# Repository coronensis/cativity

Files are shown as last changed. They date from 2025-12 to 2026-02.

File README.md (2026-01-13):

CatIVity - CAT protocol (Icom CI-V) based remote VFO tuner

This is a new iteration of CatIVity.
It is WORK IN PROGRESS and not yet fully tested.

You can find the previous version (tested and working) under v1.

## Hardware

## Software

## Development environment

Developed under GNU/Linux - [Debian](https://www.debian.org/) (Desktop) and [Raspbian](https://www.raspberrypi.org/downloads/raspbian/) (Raspberry Pi)
distributions

Toolchain and other tools/utilities used:

Desktop

- avr-gcc

Raspberry Pi

- avr-gcc
- avrdude

The provided Makefile is meant to be used on a Raspberry Pi.
Note that the reset pin of the ATmega328P is connected to pin 21 of the Raspberry
and is pulled low before starting to flash the binary to the microcontroller.

## References

- Icom's CI-V protocol specification [Computer Interface, version V](https://www.icomeurope.com/wp-content/uploads/2020/08/IC-705_ENG_CI-V_1_20200721.pdf)
- Xiegu G90 CAT protocol specification [Xiegu G90, CAT and digital modes](https://radioddity.s3.amazonaws.com/Radioddity%20-%20Xiegu%20G90%2C%20CAT%20and%20Digital%20modes%20V1.0_20210623.pdf)

## Homepage And Source Code Repository

https://github.com/coronensis/cativity

## Contact

Feel free to reach out if you run into problems building this project or want to extend or port it.

Helmut Sipos, YO6ASM <yo6asm@gmail.com>

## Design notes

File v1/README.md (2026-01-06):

CatIVity - CAT protocol (Icom CI-V) based remote VFO tuner

## Background

I recently got my amateur radio license and bought a Xiegu G90 as my first transceiver
to have something to play around with. The radio is well regarded in the ham community
and indeed does a pretty decent job for its price. That is, until it comes to tuning.

Like many other simple QRP transceivers, it has just a rudimentary VFO tuner that uses
a cheap mechanical rotary encoder with an even cheaper plastic knob mounted on it.

Such encoders tend to give up life really soon when heavily used. Additionally it is
next to impossible to efficiently tune up and down the bands. The aforementioned plastic knob
doesn't lend itself to quick operation and either you risk cramps in your fingers
or annoying delays/interruptions when changing the frequency decimal position that is
updated when you turn the knob.

As tuning around the bands looking for interesting stations to make contact with is
the main activity (at least speaking for myself) when "playing radio" that tuning behavior
of the G90 is plainly unacceptable.

Xiegu addresses that issue by selling a companion device (GSOC Touch Screen Controller)
that has a larger screen and decent knobs but that:

```
a.) Doubles the price of the setup (at which point you could look into buying an Icom 7300)
b.) Needs to be carried around as well if you are operating mostly portable, like myself.
```

As I was willing to accept neither a.) nor b.) I looked for an alternative and came up
with the solution implemented in this project.

## Solution

The G90 can be controlled via UART using a CAT protocol (more precisely: an Icom CI-V flavor)
so it is easy to implement something on a microcontroller that has a UART on it (alternatively
you can implement a "bit banged" software-UART if it doesn't) and that somehow determines the
frequency to be set, then instructs the G90 to tune to the determined frequency.

I chose to use two potentiometers (potentiometers are dirt cheap and can easily be replaced
when worn out) as the tuning knobs and to control with them the lower 5 decimal position of the
frequency.  More precisely the upper 4 of the lower 5 as the last decimal position is always 0 -
the minimum tuning step for the G90 is 10 Hz.
As the multifunction knob on the G90 can be configured to set the 6th decimal point (100k frequency
step) and there are buttons to change the bands, tuning becomes quite fluent.
The only awkward thing about that decision is that a potentiometer needs to be "reset" manually by
turning it back to its initial position. Alternatively you can tune one time upwards to 99 then
downwards to 0, which makes no difference to the frequency range scanned.

The implementation is pretty straight forward:

First synchronize with the G90 to get the current frequency it is tuned to. That frequency can
change anytime due to user intervention so it needs to be fetched every time before sending
a "SetActiveVFOFrequency" command. The CI-V command to get the frequency is "GetActiveVFOFrequency".

Once the current frequency is known, read the value of the ADC channels to which the two potentiometers
are attached (let's call them (L)eft and (R)ight). The potentiometers form a voltage divider and the
value read by the ADC reflects their relative position to zero volt. When the potentiometer is completely
"down" the ADC reads 0, conversely it will read the maximum value 1024 (the ADC works with 10 bits)
when the pot is completely "up". Dividing the ADC value by 10 brings it into range for what is needed
(0..99) and as a nice side effect also acts as a debouncing mechanism.

The next step is to construct the "SetActiveVFOFrequency" message with the read and translated ADC values
and send it to the radio then wait for the response of the radio. Then "rinse and repeat".

Example:

Lets say the current frequency set on the radio is 14198760 Hz. The ADC value 23 for the Left pot
and 45 for the right pot were read. Next the value 98 in the current frequency is substituted for 23
and 76 for 45 resulting in the frequency-to-be set 14123450 Hz.

```
 14 198 760 <- Currently frequency on the radio
     || ||
     23 45  <- Left and Right pot values read form ADC
     || ||
 14 123 450 <-  Final frequency that will be requested via "SetActiveVFOFrequency"
```

This frequency is translated into the specific protocol message byte sequence (look into the protocol
specification (links in the references section below) for how the data is encoded) and sent to the G90.

The implementation was done on a spare ATmega328P which has a hardware UART and ADC on it.
It is less than 300 lines of code (including comments and blanks).

While this toy is Xiegu G90 specific it should be really easy to port it to any other radio
that supports the CI-V protocol.

73! Helmut, YO6ASM

## Hardware

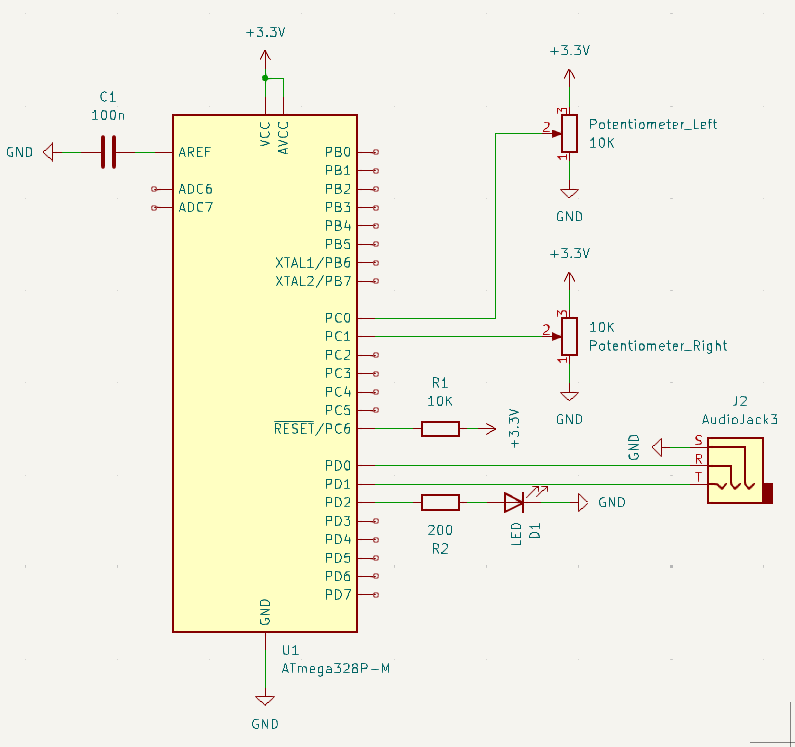
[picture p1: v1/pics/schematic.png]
CatIVity Schematic


```
1 x Atmel (Microchip) ATmega328P microcontroller - PDIP package
1 x red LED
2 x 10K potentiometer
1 x 100n capacitor
2 x 10K resistor
1 x 200ohm resistor
1 x Stereo audio jack
2 x Stereo audio plug (to make the cable to connect to the G90)

2 x Platic knob (recycled original G90 knobs)
1 x Platic housing (in this example: an old bicycle tire repair kit)
```

## Software

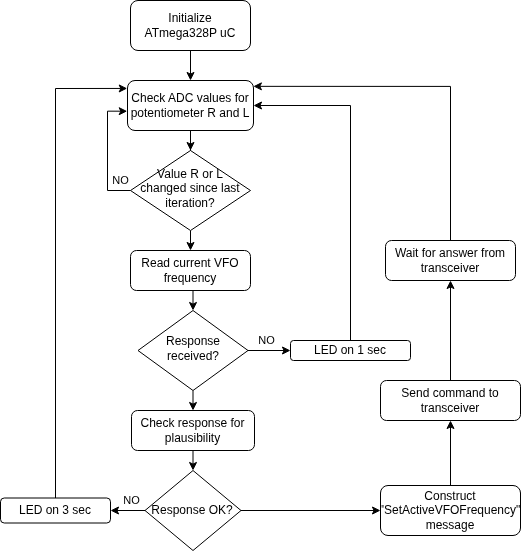
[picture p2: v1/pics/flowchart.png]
CatIVity Flowchart


## TODO

```
In a next iteration replace the potentiometers with a single optical rotary encoder and a
large tuning knob.
Add an LCD display for displaying the frequency and other status information.
Add a few buttons and make their function configurable via a dedicated PC application.
Larger housing to accommodate the additional space needed by the above additions.
```

## Pictures

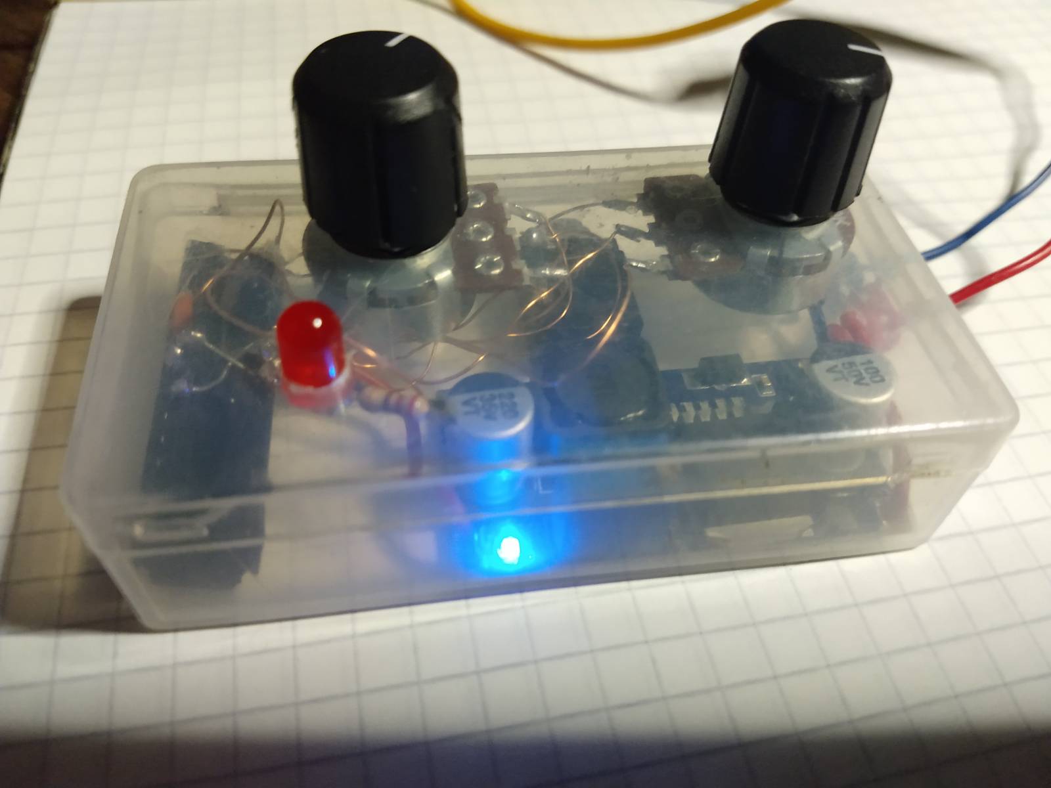
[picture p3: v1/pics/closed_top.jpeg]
Top

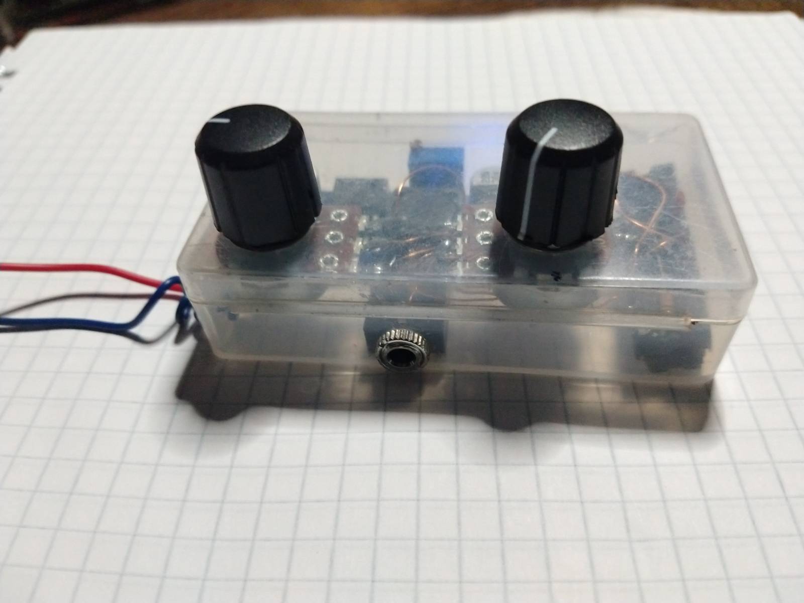
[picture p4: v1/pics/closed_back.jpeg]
Back

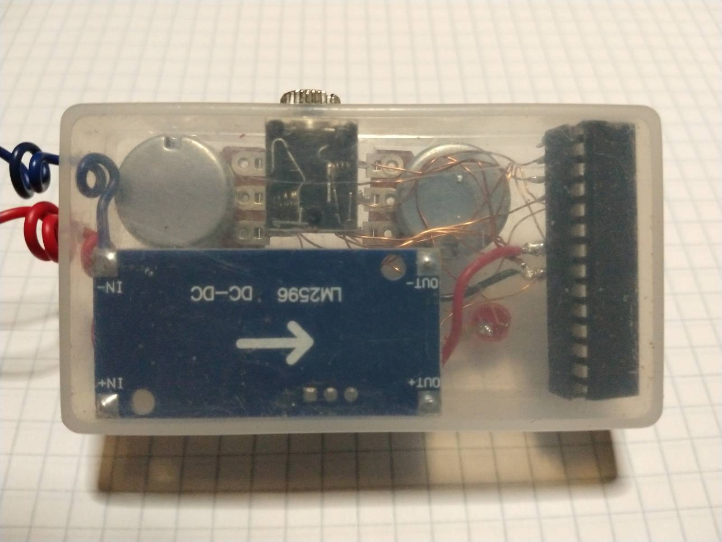
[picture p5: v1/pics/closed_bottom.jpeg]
Bottom

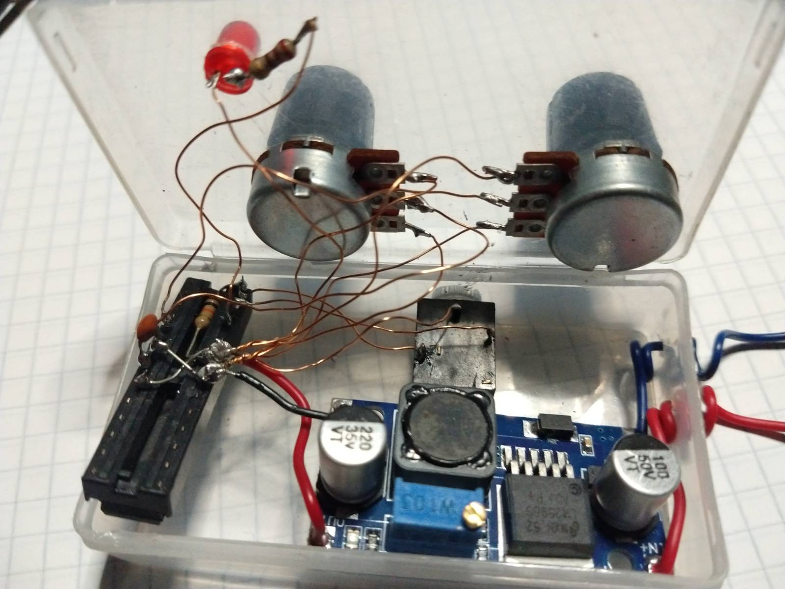
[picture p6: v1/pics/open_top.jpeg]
Open

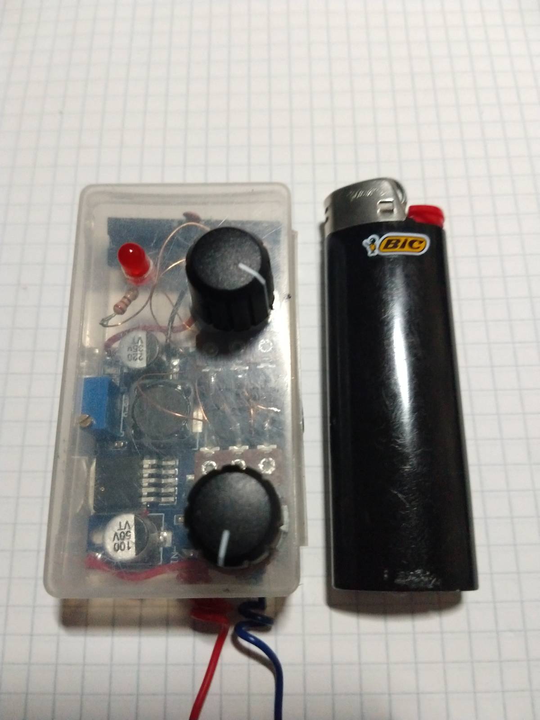
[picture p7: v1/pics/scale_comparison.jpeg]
Size


## Development environment

Developed under GNU/Linux - [Debian](https://www.debian.org/) (Desktop) and [Raspbian](https://www.raspberrypi.org/downloads/raspbian/) (Raspberry Pi)
distributions

Toolchain and other tools/utilities used:

Desktop

- avr-gcc

Raspberry Pi

- avr-gcc
- avrdude

The provided Makefile is meant to be used on a Raspberry Pi.
Note that the reset pin of the ATmega328P is connected to pin 21 of the Raspberry
and is pulled low before starting to flash the binary to the microcontroller.

## References

- Icom's CI-V protocol specification [Computer Interface, version V](https://www.icomeurope.com/wp-content/uploads/2020/08/IC-705_ENG_CI-V_1_20200721.pdf)
- Xiegu G90 CAT protocol specification [Xiegu G90, CAT and digital modes](https://radioddity.s3.amazonaws.com/Radioddity%20-%20Xiegu%20G90%2C%20CAT%20and%20Digital%20modes%20V1.0_20210623.pdf)

## Homepage And Source Code Repository

https://github.com/coronensis/cativity

## Contact

Feel free to reach out if you run into problems building this project or want to extend or port it.

Helmut Sipos, YO6ASM <yo6asm@gmail.com>

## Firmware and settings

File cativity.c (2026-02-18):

/*
 * CatIVity - CAT protocol (Icom CI-V) based remote VFO tuner
 *
 * Copyright (c) 2026 Helmut Sipos, YO6ASM <yo6asm@gmail.com>
 * All rights reserved.
 *
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
 * THIS SOFTWARE IS PROVIDED BY THE COPYRIGHT HOLDERS AND CONTRIBUTORS "AS IS" AND
 * ANY EXPRESS OR IMPLIED WARRANTIES, INCLUDING, BUT NOT LIMITED TO, THE IMPLIED
 * WARRANTIES OF MERCHANTABILITY AND FITNESS FOR A PARTICULAR PURPOSE ARE
 * DISCLAIMED. IN NO EVENT SHALL THE COPYRIGHT OWNER OR CONTRIBUTORS BE LIABLE FOR
 * ANY DIRECT, INDIRECT, INCIDENTAL, SPECIAL, EXEMPLARY, OR CONSEQUENTIAL DAMAGES
 * (INCLUDING, BUT NOT LIMITED TO, PROCUREMENT OF SUBSTITUTE GOODS OR SERVICES;
 * LOSS OF USE, DATA, OR PROFITS; OR BUSINESS INTERRUPTION) HOWEVER CAUSED AND
 * ON ANY THEORY OF LIABILITY, WHETHER IN CONTRACT, STRICT LIABILITY, OR TORT
 * (INCLUDING NEGLIGENCE OR OTHERWISE) ARISING IN ANY WAY OUT OF THE USE OF THIS
 * SOFTWARE, EVEN IF ADVISED OF THE POSSIBILITY OF SUCH DAMAGE.
 */

#include <avr/io.h>
#include <avr/interrupt.h>
#include <util/delay.h>
#include <stdint.h>

// States of the indicator LED
#define LED_OFF                      0
#define LED_ON                       1

// UART default baudate
#define UART_BAUDRATE                19200

// CI-V protocol elements
#define CIV_PREAMBLE                 0xFE
#define CIV_TRANSCEIVER_ADDRESS      0x70
#define CIV_CONTROLLER_ADDRESS       0xE0
#define CIV_END_OF_MESSAGE           0xFD
#define CIV_GET_ACTIVE_VFO_FREQUENCY 0x03
#define CIV_SET_ACTIVE_VFO_FREQUENCY 0x05

// Supported VFO frequency range 0.5 - 30.0 MHz
#define VFO_FRQUENCY_MIN             500000
#define VFO_FRQUENCY_MAX             30000000

// Pulses per rotation (x 2 as there is one on 'A' AND 'B')
#define ROTARY_ENCODER_PULSES_PER_ROTATION (600 * 2)

// Number of complete rotations per second. Determines the tuning steps.
// The faster the knob is spun, the lager the tuning steps.
volatile uint8_t gRotationsPerSecond = 0;

// RX buffer
volatile uint8_t gUartRXBuffer[64];
// Counter indicating how many bytes are in the RX buffer
volatile uint8_t gUartRXBytes = 0;

// The VFO frequency
volatile uint32_t gVFOFrequency = 0;
// Frequency increment/decrement step
volatile uint8_t gVFOFrequencyStep = 0;
// VFO synchronized with tranceiver indicator flag
volatile uint8_t gVFOFrequencyValid = 0;

// Number of pulses per time unit (1000ms) received from the rotary encoder
volatile uint16_t gEncoderPulses = 0;

// VFO frequency tuning increment/decrement steps
const uint8_t gTuningSteps[] = {1, 2, 3, 4, 5, 10};
#define TUNING_STEPS_IDX_MAX ((sizeof(gTuningSteps)/sizeof(gTuningSteps[0])) - 1)

// Keeps the time since last sync with the transceiver
volatile uint8_t gSecondsSinceLastSync = 0;

// External INT0 (PD2, rotary encoder 'A') interrupt service routine
ISR(INT0_vect)
{
    gEncoderPulses++;

    // Rotation RIGHT?
    if (bit_is_set(PIND, PIND3)) {
        gVFOFrequency += gVFOFrequencyStep;
    }
}

// External INT1 (PD3, rotary encoder 'B') interrupt service routine
ISR(INT1_vect)
{
    gEncoderPulses++;

    // Rotation LEFT?
    if (bit_is_set(PIND, PIND2)) {
        gVFOFrequency -= gVFOFrequencyStep;
    }
}

// UART RX interrupt service routine
ISR(USART_RX_vect)
{
    // Copy the received byte inito the buffer if there is space left
    // Increment the counter indicating how many bytes are in the buffer
    if (gUartRXBytes < sizeof(gUartRXBuffer)) {
        gUartRXBuffer[gUartRXBytes] = UDR0;
        gUartRXBytes++;
    }
}

// Timer1 overflow interrupt service routine
ISR(TIMER1_OVF_vect)
{
    // Setup for new timer overflow interrupt after 1000ms
    TCNT1H = 0x85;
    TCNT1L = 0xEE;

    gSecondsSinceLastSync++;

    gRotationsPerSecond = gEncoderPulses / ROTARY_ENCODER_PULSES_PER_ROTATION;
    gEncoderPulses = 0;
    if (gRotationsPerSecond > TUNING_STEPS_IDX_MAX) {
        gRotationsPerSecond = TUNING_STEPS_IDX_MAX;
    }

    gVFOFrequencyStep = gTuningSteps[gRotationsPerSecond];
}

// Set red LED to ON or OFF
void led_red(uint8_t state)
{
    if (state == LED_ON) {
        PORTD |= _BV(PORTD4);
    }
    else {
        PORTD &= ~_BV(PORTD4);
    }
}

// Send an array of bytes through the UART
void uart_send(const uint8_t *data, uint8_t length)
{
    for (int i = 0; i < length; ++i) {
        // Wait for empty transmit buffer
        while (bit_is_clear(UCSR0A, UDRE0)) {
        }

        // Put tx data into the buffer. It will then be send by the hardware
        UDR0 = data[i];
    }
}

// Convert frequency Hz -> 5-byte BCD LSB-first
void frequency_to_bcd(uint32_t frequency, uint8_t *out)
{
    uint8_t decimals[10];

    // Get the decimal for each position
    for (int i = 0; i < 10; ++i) {
        decimals[i] = frequency % 10;
        frequency /= 10;
    }

    // Pack the decimals into the byte array
    out[0] = (decimals[1] << 4) | decimals[0];
    out[1] = (decimals[3] << 4) | decimals[2];
    out[2] = (decimals[5] << 4) | decimals[4];
    out[3] = (decimals[7] << 4) | decimals[6];
    out[4] = (decimals[9] << 4) | decimals[8];
}

// Convert 5-byte BCD LSB-first -> frequency Hz. Return 0 if invalid (any nibble >9)
uint32_t bcd_to_frequency(volatile const uint8_t *const data)
{
    uint8_t decimals[10];

    // Unpack the decimals from the byte array
    decimals[0] = data[0] & 0x0F;
    decimals[1] = (data[0] >> 4) & 0x0F;
    decimals[2] = data[1] & 0x0F;
    decimals[3] = (data[1] >> 4) & 0x0F;
    decimals[4] = data[2] & 0x0F;
    decimals[5] = (data[2] >> 4) & 0x0F;
    decimals[6] = data[3] & 0x0F;
    decimals[7] = (data[3] >> 4) & 0x0F;
    decimals[8] = data[4] & 0x0F;
    decimals[9] = (data[4] >> 4) & 0x0F;

    // Check for plausible value
    for (int i = 0; i < 10; ++i) {
        if (decimals[i] > 9) {
            return 0;
        }
    }

    uint32_t frequency = 0;
    uint32_t mul = 1;

    // Assemble the frequency value from the decimals
    for (int i = 0; i < 10; ++i) {
        frequency += decimals[i] * mul;
        mul *= 10;
    }

    return frequency;
}

// Retrieve the currently set VFO frequency from the transceiver
uint32_t get_current_vfo_frequency(void)
{
    uint8_t timeout_counter = 0x00;
    uint32_t frequency = 0x00;

    // See CI-V protocol specification for message details
    const uint8_t cmdGetActiveVFOFrequency[] = {
        CIV_PREAMBLE,
        CIV_PREAMBLE,
        CIV_TRANSCEIVER_ADDRESS,
        CIV_CONTROLLER_ADDRESS,
        CIV_GET_ACTIVE_VFO_FREQUENCY,
        CIV_END_OF_MESSAGE
    };

    // Request the current frequency from the transceiver
    // Xiegu G90 is echoing back the received command and THEN sending the response
    // therefore we need to wait for both messages.
    gUartRXBytes = 0;
    uart_send(cmdGetActiveVFOFrequency, sizeof(cmdGetActiveVFOFrequency) / sizeof(cmdGetActiveVFOFrequency[0]));
    timeout_counter = 50;
    while ((gUartRXBytes < 17) && --timeout_counter) {
        _delay_ms(1);
    }

    if (timeout_counter == 0) {
        // RX Timeout
        led_red(LED_ON);
        _delay_ms(1000);
        led_red(LED_OFF);
        _delay_ms(1000);
    }
    else {
        // Check message for plausibility
        if (       (gUartRXBuffer[6] == CIV_PREAMBLE)
                && (gUartRXBuffer[7] == CIV_PREAMBLE)
                && (gUartRXBuffer[8] == CIV_CONTROLLER_ADDRESS)
                && (gUartRXBuffer[9] == CIV_TRANSCEIVER_ADDRESS)
                && (gUartRXBuffer[10] == CIV_GET_ACTIVE_VFO_FREQUENCY)
                && (gUartRXBuffer[16] == CIV_END_OF_MESSAGE)
           ) {
            // decode the frequency from the received response
            frequency = bcd_to_frequency(&gUartRXBuffer[11]);
        }
        else {
            // Malformed message
            led_red(LED_ON);
            _delay_ms(3000);
            led_red(LED_OFF);
            _delay_ms(3000);
        }
    }

    return frequency;
}

// Initialize the MCU
void init_hardware(void)
{
    // Initialize Ports

    // Port B all inputs
    DDRB  = 0b00000000;
    // Pulls-ups for all inputs
    PORTB = 0b11111111;

    // Port C all inputs
    DDRC  = 0b00000000;
    // Pulls-ups for all inputs
    PORTC = 0b11111111;

    // Port D - all inputs except UART TX (PD1) and LED (PD4)
    DDRD  = 0b00010010;
    // Enable internal pull-ups for all but UART TX and LED
    PORTD = 0b11101101;

    // Initialize external interrupts

    // External interrupts 0,1: Select falling edge trigger
    EICRA = 0b00001010;
    // Enable External Interrupts
    EIMSK = 0b00000011;

    // Initialize UART

    // Set format N81 and baud rate
    UBRR0 = (uint8_t)((F_CPU / UART_BAUDRATE + 8) / 16 - 1);
    // Enable receiver and transmitter as well as receive interrupt
    UCSR0B = (1 << RXEN0) | (1 << TXEN0) | (1 << RXCIE0);

    // Initialize Timer1

    TCCR1A = 0x00;
    // 1:256 prescaler
    TCCR1B = 0x04;
    TCCR1C = 0x00;
    // Enable overflow interrupt
    TIMSK1 = 0x01;
    // Timer overflows after 1000ms
    TCNT1H = 0x85;
    TCNT1L = 0xEE;
}

int main(void)
{
    uint8_t timeout_counter = 0x00;

    uint32_t last_vfo_frequency = 0x00;

    // See CI-V protocol specification for message details
    uint8_t cmdSetActiveVFOFrequency[] = {
        CIV_PREAMBLE,
        CIV_PREAMBLE,
        CIV_TRANSCEIVER_ADDRESS,
        CIV_CONTROLLER_ADDRESS,
        CIV_SET_ACTIVE_VFO_FREQUENCY,
        0x00, 0x00, 0x00, 0x00, 0x00, // Frequency -> BCD coded
        CIV_END_OF_MESSAGE
    };

    // Disable interrupts while setting things up
    cli();

    // Initialize the microcontroller
    init_hardware();

    // Enable interrupts
    sei();

    // Forever
    for (;;) {

        // If not done so yet, retrieve the current frequency from the transceiver
        if (!gVFOFrequencyValid) {

            if (!((gVFOFrequency = get_current_vfo_frequency()))) {
                continue;
            }

            gVFOFrequencyValid = 1;
        }

        // Clamp the frequency to the supported range
        if (gVFOFrequency < VFO_FRQUENCY_MIN)
        {
            gVFOFrequency = VFO_FRQUENCY_MIN;
        }
        else if (gVFOFrequency > VFO_FRQUENCY_MAX)
        {
            gVFOFrequency = VFO_FRQUENCY_MAX;
        }

        // Do nothing while the frequency didn't change
        if (gVFOFrequency == last_vfo_frequency) {
            // In moments of inactivity sync every 3 seconds with the transceiver
            // (in case the frequency on it was manually changed)
            if (gSecondsSinceLastSync >= 3) {
                gVFOFrequencyValid = 0;
            }
            continue;
        }

        // Reset - the frequency is set hence sync is done
        gSecondsSinceLastSync = 0;

        // Update last values
        last_vfo_frequency = gVFOFrequency;

        // Encode the frequency in BCD as per spec.
        frequency_to_bcd(gVFOFrequency, &cmdSetActiveVFOFrequency[5]);

        // Send the current frequency to the transceiver
        // then read (and ignore) the response
        gUartRXBytes = 0;
        uart_send(cmdSetActiveVFOFrequency, sizeof(cmdSetActiveVFOFrequency) / sizeof(cmdSetActiveVFOFrequency[0]));
        timeout_counter = 50;
        while ((gUartRXBytes < 17) && --timeout_counter) {
            _delay_ms(1);
        }
    }
}

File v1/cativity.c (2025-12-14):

/*
 * CatIVity - CAT protocol (Icom CI-V) based VFO tuner
 *
 * Copyright (c) 2025 Helmut Sipos, YO6ASM <yo6asm@gmail.com>
 * All rights reserved.
 *
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
 * THIS SOFTWARE IS PROVIDED BY THE COPYRIGHT HOLDERS AND CONTRIBUTORS "AS IS" AND
 * ANY EXPRESS OR IMPLIED WARRANTIES, INCLUDING, BUT NOT LIMITED TO, THE IMPLIED
 * WARRANTIES OF MERCHANTABILITY AND FITNESS FOR A PARTICULAR PURPOSE ARE
 * DISCLAIMED. IN NO EVENT SHALL THE COPYRIGHT OWNER OR CONTRIBUTORS BE LIABLE FOR
 * ANY DIRECT, INDIRECT, INCIDENTAL, SPECIAL, EXEMPLARY, OR CONSEQUENTIAL DAMAGES
 * (INCLUDING, BUT NOT LIMITED TO, PROCUREMENT OF SUBSTITUTE GOODS OR SERVICES;
 * LOSS OF USE, DATA, OR PROFITS; OR BUSINESS INTERRUPTION) HOWEVER CAUSED AND
 * ON ANY THEORY OF LIABILITY, WHETHER IN CONTRACT, STRICT LIABILITY, OR TORT
 * (INCLUDING NEGLIGENCE OR OTHERWISE) ARISING IN ANY WAY OUT OF THE USE OF THIS
 * SOFTWARE, EVEN IF ADVISED OF THE POSSIBILITY OF SUCH DAMAGE.
 */

#include <avr/io.h>
#include <avr/interrupt.h>
#include <util/delay.h>
#include <stdint.h>

// Xiegu G90's CI-V protocol baudrate
#define UART_BAUDRATE                19200

#define ADC_CHANNEL_POT_LEFT         0
#define ADC_CHANNEL_POT_RIGHT        1

#define LED_RED                      PD2
#define LED_OFF                      0
#define LED_ON                       1

#define CIV_PREAMBLE                 0xFE

// Xiegu G90 default address (also responds to 0x88 etc.)
#define CIV_TRANSCEIVER_ADDRESS      0x70
#define CIV_CONTROLLER_ADDRESS       0xE0
#define CIV_END_OF_MESSAGE           0xFD

#define CIV_GET_ACTIVE_VFO_FREQUENCY 0x03
#define CIV_SET_ACTIVE_VFO_FREQUENCY 0x05

// See CI-V protocol specification for message details
const uint8_t cmdGetActiveVFOFrequency[] = {
    CIV_PREAMBLE,
    CIV_PREAMBLE,
    CIV_TRANSCEIVER_ADDRESS,
    CIV_CONTROLLER_ADDRESS,
    CIV_GET_ACTIVE_VFO_FREQUENCY,
    CIV_END_OF_MESSAGE
};

// RX buffer
volatile uint8_t uart_rx_buffer[64];
// Counter indicating how many bytes are in the RX buffer
volatile uint8_t uart_rx_bytes = 0x00;

// Digitized voltage set by the voltage divider right potentiometer
volatile uint8_t right_pot_value = 0x00;

// Digitized voltage set by the voltage divider right potentiometer
volatile uint8_t left_pot_value = 0x00;

// UART service routine
ISR(USART_RX_vect)
{
    // Copy the received byte inito the buffer if there is space left
    // Increment the counter indicating how many bytes are in the buffer
    if (uart_rx_bytes < sizeof(uart_rx_buffer)) {
        uart_rx_buffer[uart_rx_bytes] = UDR0;
        uart_rx_bytes++;
    }
}

// ADC service routine
ISR(ADC_vect)
{
    uint8_t adc_l = ADCL;
    uint8_t adc_h = ADCH;
    // The ADC conversion is a 10 bit value -> values range from 0...1024
    // Diving by  10 puts it nicely into our desired range of 0..99
    uint16_t adc_val = ((adc_h << 8) | adc_l) / 10;

    // Clamp the value to 0..100
    if (adc_val > 100) {
        adc_val = 100;
    }

    // Alternatively read the value set by pot right and left
    if (ADMUX & ADC_CHANNEL_POT_RIGHT) {
        right_pot_value = (right_pot_value + adc_val) / 2;
        ADMUX = 0x40 | ADC_CHANNEL_POT_LEFT;
    }
    else {
        left_pot_value = (left_pot_value + adc_val) / 2;
        ADMUX = 0x40 | ADC_CHANNEL_POT_RIGHT;
    }
}

// TIMER 1 service routine
ISR(TIMER1_OVF_vect)
{
    // Another interrupt will occur after ~50ms due to timer overflow
    // TIMER1 overflow triggers the ADC
    TCNT1L = 0xB0;
    TCNT1H = 0x3C;
}

// Set red led to ON or OFF
void led_red(uint8_t state)
{
    if (state == LED_ON) {
        PORTD |= _BV(LED_RED);
    }
    else {
        PORTD &= ~_BV(LED_RED);
    }
}

// Send an array of bytes through the UART
void uart_send(const uint8_t *data, uint8_t length)
{
    for (int i = 0; i < length; ++i) {
        // Wait for empty transmit buffer
        while (bit_is_clear(UCSR0A, UDRE0)) {
        }

        // Put tx data into the buffer. It will then be send by the hardware
        UDR0 = data[i];
    }
}

int main(void)
{
    uint8_t oneHzTenHz = 0x00;
    uint8_t hundredHzOneKHz = 0x00;
    uint8_t tenKHzHundredKHz = 0x00;
    uint8_t oneMHzTenMHz = 0x00;

    uint8_t last_right_pot_value = 0x00;
    uint8_t last_left_pot_value = 0x00;

    uint8_t timeout_counter = 0x00;

    // See CI-V protocol specification for message details
    uint8_t cmdSetActiveVFOFrequency[] = {
        CIV_PREAMBLE,
        CIV_PREAMBLE,
        CIV_TRANSCEIVER_ADDRESS,
        CIV_CONTROLLER_ADDRESS,
        CIV_SET_ACTIVE_VFO_FREQUENCY,
        0x00, 0x00, 0x00, 0x00, 0x00, // Frequency -> BCD coded
        CIV_END_OF_MESSAGE
    };

    // Disable interrupts while setting things up
    cli();

    // Initialize Ports
    // Port B all inputs
    DDRB  = 0x00;
    // Pulls-ups for inputs
    PORTB = 0xFF;

    // Port C all inputs C0 and C1 -> ADC
    DDRC  = 0x00;
    // Enable pull-ups for uppermost 2 bits
    PORTC = 0xF0;

    // Port D - all inputs except UART TX and LED (PD1 and PD2)
    DDRD  = 0x06;
    // Enable internal pull-ups for all but RX and TX
    PORTD = 0xF9;

    // Initialize Timer1
    TCCR1A = 0x00;
    // 1:8 prescaler
    TCCR1B = 0x02;
    TCCR1C = 0x00;
    // Enable TC1.ovf interrupt
    TIMSK1 = 0x01;
    // Interrupt after 50ms due to timer overflow
    TCNT1L = 0xB0;
    TCNT1H = 0x3C;

    // Initialize UART set format N81, enable RX, TX and RX interrupt
    UBRR0 = (uint8_t)((F_CPU / UART_BAUDRATE + 8) / 16 - 1);
    UCSR0B = (1 << RXEN0) | (1 << TXEN0) | (1 << RXCIE0); // Enable RX, TX, and RX interrupt

    // Initialize ADC
    // AVCC with external capacitor at AREF pin, align right, chanel 0
    ADMUX = 0x40;

    // Enable ADC, auto trigger, enable interrupt, prescaler = 64 -> result in 125KHz sampling rate
    ADCSRA = 0xEE;

    // ADC TIMER1 overflow mode. Free running mode would mean interrupts every 200us
    ADCSRB = 0x06;
    // Disable analog comp
    ACSR   = 0x80;

    // Disable ditital input for the analog input channels
    DIDR0 |= (1 << ADC1D) | (1 << ADC0D);

    // Enable interrupts
    sei();

    // Forever
    for (;;) {

        // Turn the red LED off and delay 300 ms
        led_red(LED_OFF);
        _delay_ms(300);

        // Do nothing while the potentiometers have not moved
        if ((right_pot_value == last_right_pot_value)
            &&
            (left_pot_value == last_left_pot_value)
           ) {
            continue;
        }

        // Update last values
        last_right_pot_value = right_pot_value;
        last_left_pot_value = left_pot_value;

        // Request the current frequency from the radio
        uart_rx_bytes = 0;
        uart_send(cmdGetActiveVFOFrequency, sizeof(cmdGetActiveVFOFrequency));

        // Xiegu G90 is echoing back the received command and THEN sending the response
        // therefore we need to wait for both messages.
        timeout_counter = 50;
        while ((uart_rx_bytes < 17) && --timeout_counter) {
            _delay_ms(1);
        }
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

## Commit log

2025-12-14 Added schematic and some pictures
    [cativity.kicad_pcb, cativity.kicad_sch]
2025-12-17 Updated BOM
2025-12-24 Updated documentation and schematic
2026-01-06 Improve project structure
    [cativity.kicad_pcb, cativity.kicad_sch]
2026-01-13 Preserve version v1
    [cativity.kicad_pcb, cativity.kicad_sch]
2026-01-13 New iteration using an optical rotary encoder
2026-02-15 Fixed RX from transceiver and cleaned up code
    [cativity.c]
